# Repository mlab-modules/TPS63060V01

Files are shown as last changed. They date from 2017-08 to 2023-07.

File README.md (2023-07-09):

# MLAB TPS63060V01A Module

The MLAB TPS63060V01A module is based on [TPS63060](https://www.ti.com/lit/ds/symlink/tps63060.pdf?HQS=TI-null-null-digikeymode-df-pf-null-wwe&ts=1614085886440) integrated circuit from Texas Instruments. This circuit is a synchronous step-down (buck-boost) converter, capable of regulating the output voltage whether the input voltage is either higher or lower than the output voltage.

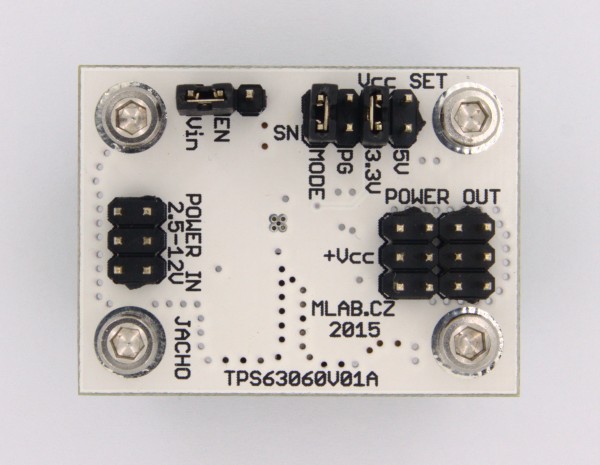
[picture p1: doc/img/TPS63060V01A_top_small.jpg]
TPS63060V01A


### TPS63060
The TPS63060 is a highly efficient, fully integrated, synchronous buck-boost converter designed for a wide range of applications. This circuit has an internal switching transistor, which allows it to achieve high efficiency at low loads.

The TPS63060 operates in automatic PFM/PWM switching mode, switching between PFM (Pulse Frequency Modulation) mode at low loads for efficiency optimization, and PWM (Pulse Width Modulation) mode at higher loads for better voltage regulation.

### Basic Parameters:
- Input voltage: 2.5 V to 12 V
- Output voltage: 2.5 V to 8 V
- Maximum current for internal transistor: 2 A
- Output voltage selectable at 3.3 V or 5 V (by jumper placement)
- Pin for converter activation: EN
- Pin for power saving mode and synchronization: PS/SYNC

Users can choose between an output voltage of 3.3 V or 5 V using a jumper setting.

A significant feature of the module is the ability to activate and deactivate the converter via the EN (enable input) pin. This is especially useful in applications where power is supplied by batteries, and there is a need to protect them from deep discharge.

A unique feature of the module is also the presence of the PS/SYNC pin, labeled as SN. This allows the power saving mode of the converter to be activated if the current draw is less than 100 mA. This pin can also be used to synchronize the converter with an external clock signal.

## Possible Applications
Due to its range of input and output voltages and the ability to regulate, this module is suitable for various applications. It can be used to power low voltage devices from higher voltage batteries or vice versa. Its versatility makes it suitable for a wide range of devices from mobile devices to IoT applications to industrial systems. The power saving mode and the ability to activate/deactivate the converter also support its use in devices where power consumption efficiency is important.

For more detailed information on the functionality of the TPS63060 circuit, we recommend studying its [technical datasheet](https://www.ti.com/lit/ds/symlink/tps63060.pdf?HQS=TI-null-null-digikeymode-df-pf-null-wwe&ts=1614085886440). If you have any further questions, feel free to contact us via email or [Github discuss page](https://github.com/orgs/MLAB-project/discussions) for more information and resources.

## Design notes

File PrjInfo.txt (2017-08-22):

[InfoShortDescription.en]
BUCK-BOOST CONVERTER

[InfoShortDescription.cs]
Snižující/Zvyšující měnič

[InfoLongDescription.en]
The drive uses the TPS63060 circuit. The input voltage range of 2.5 V - 12V. The output voltage of 3.3 V, 5 V. 

[InfoLongDescription.cs]
Měnič využívá obvodu TPS63060. Vstupní napětí v rozsahu 2,5 V - 12V. Výstupní napětí 3,3 V, 5 V. 

[InfoBuyUST]
http://www.ust.cz/shop/product_info.php?cPath=22_35&products_id=258

[End]

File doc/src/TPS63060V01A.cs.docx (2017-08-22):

Snižující / zvyšující měnič

Jan Chroust

## Měnič využívá obvodu TPS63060. Vstupní napětí v rozsahu 2,5 V - 12V. Výstupní napětí 3,3 V, 5 V.

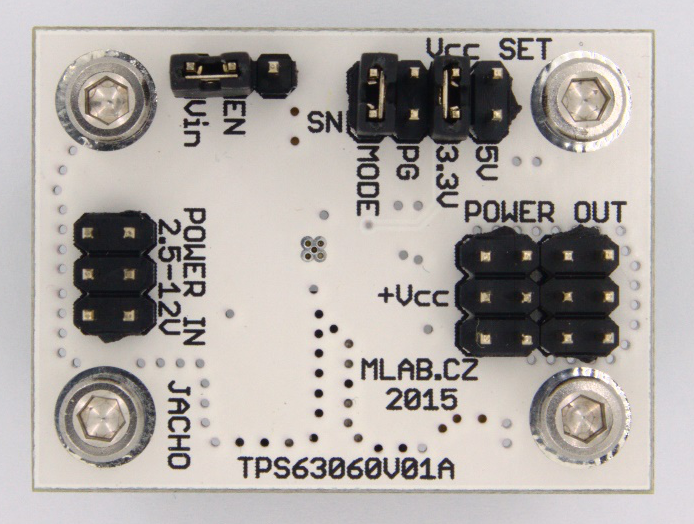
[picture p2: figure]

# 1. Technické parametry

Parametr | Hodnota | Poznámka
Napájení | 2,5 V – 12 V
Výstupní napětí | 3,3V nebo 5 V | Změnou součástek 2,5 V – 8 V
Integrovaný obvod | TPS63060
Imax vnitřním tranzistorem | cca 2,25 A
Rozměry | 29.97 x 40.13 x 16 mm | Výška nad základní deskou

# 2. Popis konstrukce

Základ celého modulu tvoří obvod TPS63060, který umožňuje měnit vstupní stejnosměrné napětí v rozsahu 2,5 V až 12 V na výstupní napětí v rozsahu 2,5 V až 8 V. Maximální proud pro vnitřní tranzistor je cca 2,25A. Modul je standardně osazen rezistory pro fixní nastavení výstupního napětí 3,3 V nebo 5 V, které se volí pomocí jumperu.

Pin EN (enable input) slouží pro aktivaci měniče. Tento vývod je důležitý pro aplikace, které se napájejí z akumulátorů a je potřeba zajistit, aby se měnič včas vypnul a nedošlo k pod vybití akumulátorů. Pro hlídání meze vypnutí měniče je využit obvod APX809 s mezní hodnotou 2,6V. Toto napětí je vhodné pro napájení z jednoho Li-on článku.

Modul má vyvedený pin PS/SYNC na hřebínek označení SN. V případě, kdy je na pozici MODE vložen jumper, tak je modul v úsporném režimu. Tento režim se začne projevovat při odběru proudu pod 100 mA, kdy se měnič může vypínat, pokud výstupní kondenzátory udrží nastavené výstupní napětí. Úsporný režim je deaktivován nastavením log. 1 na pin SN. Tento pin je možné využít i pro synchronizaci měniče vnějším hodinovým signálem.

Podrobný popis funkcí a módů obvodu TPS63060 je možné podrobně nastudovat v technickém listu obvodu.

## 2.1. Mechanická konstrukce

Modul obsahuje úchytné šroubky ve všech rozích v rozteči MLAB (10.16mm).

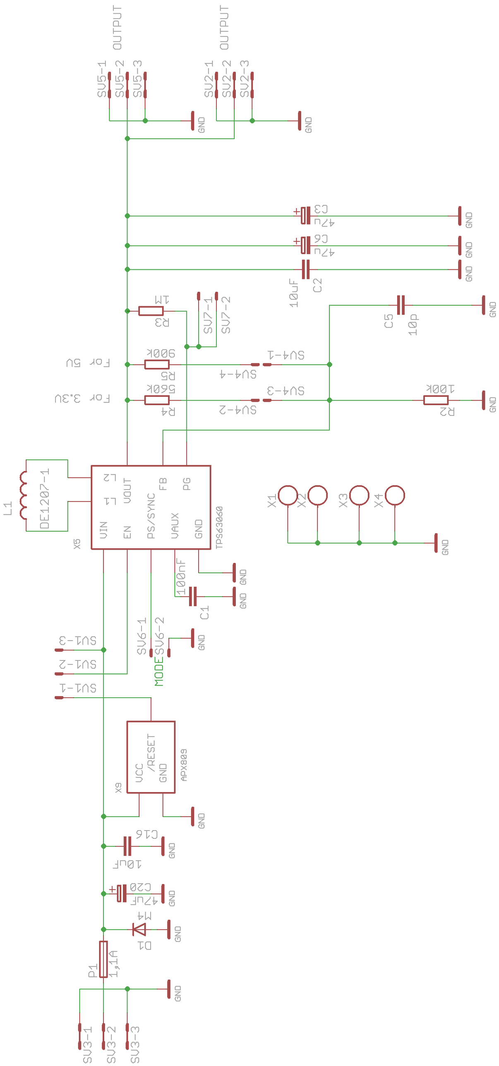
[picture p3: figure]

## 2.2. Osazení a oživení

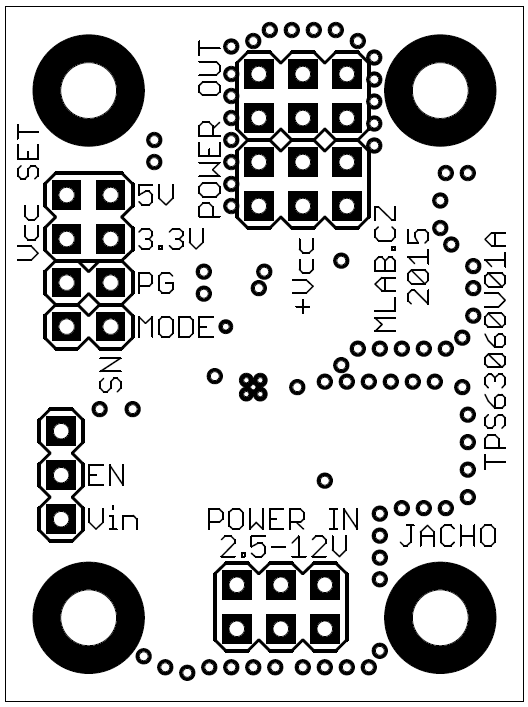
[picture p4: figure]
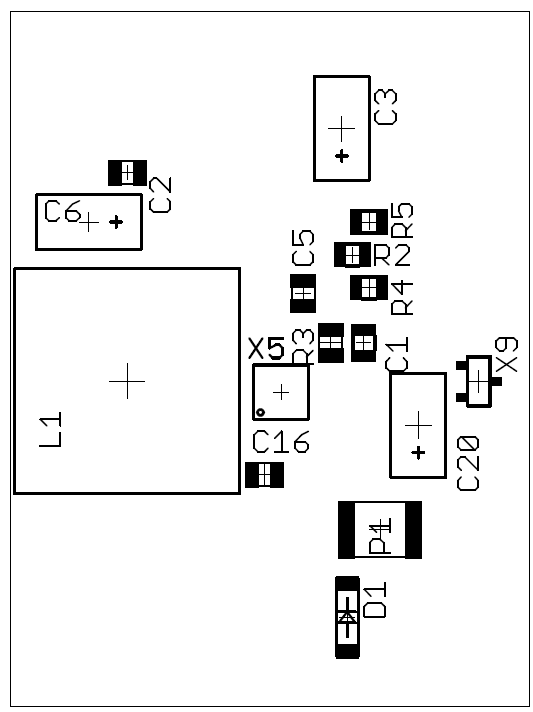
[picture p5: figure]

## 2.3. Osazení

Označení | Typ | Pouzdro | Počet
C1 | 100nF | C0805 | 1
C2, C16 | 10uF | C0805 | 2
C3, C6, C20 | 47u | C | 3
C5 | 10p | C0805 | 1
D1 | M4 | SMA | 1
L1 | DE1207-1 | DE1205-10 | 1
P1 | 1,1A | 1812 | 1
R2 | 100k | 805 | 1
R3 | 1M | 805 | 1
R4 | 560k | 805 | 1
R5 | 909k | 805 | 1
SV1 | JUMP1X3 | MA03-1 | 1
SV2, SV3, SV5 | JUMP2X3 | MA03-2 | 3
SV4 | JUMP2X2 | MA02-2 | 1
SV6, SV7 | JUMP2X1 | MA02-1 | 2
X1 - X4 | SROUB3M | SROUB3M | 4
X5 | TPS63060 | SON10 | 1
X9 | APX809 | SOT23 | 1

Jumper na pozici: MODE, 3,3 V a EN-Vin

Při osazování: zvýšená pozornost na zaletování X5, modul je možné mýt

TPS63060V01A / 2015-11-05 / jacho/ http://www.mlab.cz 4 / 4

TPS63060V01A MLAB

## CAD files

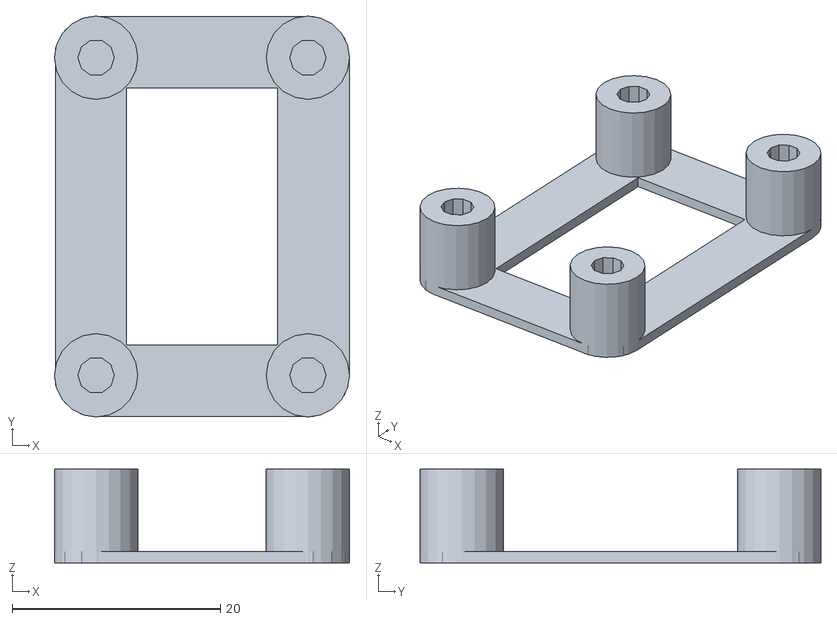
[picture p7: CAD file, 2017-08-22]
cad/3x4MLAB_frame.stl
28.3 x 38.5 x 9.00

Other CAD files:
cad/src/3x4MLAB_frame.scad

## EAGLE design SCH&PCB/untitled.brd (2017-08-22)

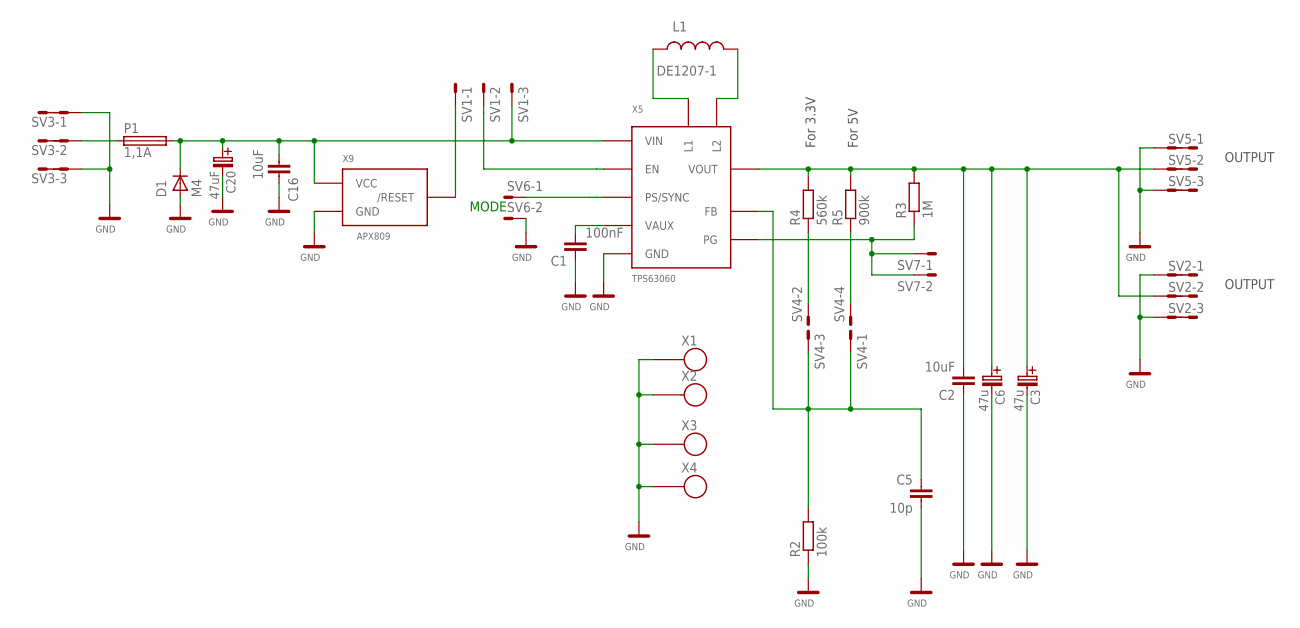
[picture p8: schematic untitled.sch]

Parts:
C1: 100nF; C0805
C2, C16: 10uF; C0805
C3, C6: 47u; C
C5: 10p; C0805
C20: 47uF; C
D1: M4; SMA
L1: DE1207-1; DE1205-10
P1: 1,1A; 1812
R2: 100k; 0805
R3: 1M; 0805
R4: 560k; 0805
R5: 900k; 0805
SV1: MA03-1
SV2, SV3, SV5: MA03-2
SV4: MA02-3; MA02-2
SV6, SV7: MA02-1
X1, X2, X3, X4: SROUB3M
X5: TPS63060; SON10
X9: APX809; SOT23

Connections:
+BAT2: C16.2, C20.+ (C_EL+), D1.K (C), P1.2, SV1.3, X5.2 (VIN), X9.3 (VCC)
GND: C1.1, C2.1, C3.- (C_EL-), C5.2, C6.- (C_EL-), C16.1, C20.- (C_EL-), D1.A, R2.1, SV2.1, SV2.2, SV2.5, SV2.6, SV3.1, SV3.2, SV3.5, SV3.6, SV5.1, SV5.2, SV5.5, SV5.6, SV6.2, X1.P$1, X2.P$1, X3.P$1, X4.P$1, X5.7 (GND), X5.11 (GND), X5.12 (GND), X5.13 (GND), X5.14 (GND), X5.15 (GND), X5.16 (GND), X5.17 (GND), X5.18 (GND), X5.19 (GND), X5.21 (GND), X5.P$1 (GND), X5.P$2 (GND), X5.P$3 (GND), X5.P$4 (GND), X5.P$5 (GND), X9.1 (GND)
unnamed: SV1.1, X9.2 (/RESET)
unnamed: SV1.2, X5.3 (EN)
unnamed: P1.1, SV3.3, SV3.4
unnamed: C5.1, R2.2, SV4.1, SV4.3, X5.8 (FB)
unnamed: R3.1, SV7.1, SV7.2, X5.5 (PG)
unnamed: R4.1, SV4.2
unnamed: C2.2, C3.+ (C_EL+), C6.+ (C_EL+), R3.2, R4.2, R5.2, SV2.3, SV2.4, SV5.3, SV5.4, X5.9 (VOUT)
unnamed: R5.1, SV4.4
unnamed: SV6.1, X5.4 (PS/SYNC)
unnamed: C1.2, X5.6 (VAUX)
unnamed: L1.P$1 (1), X5.1 (L1)
unnamed: L1.P$2 (2), X5.10 (L2)

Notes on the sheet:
OUTPUT
MODE
For 5V
For 3.3V

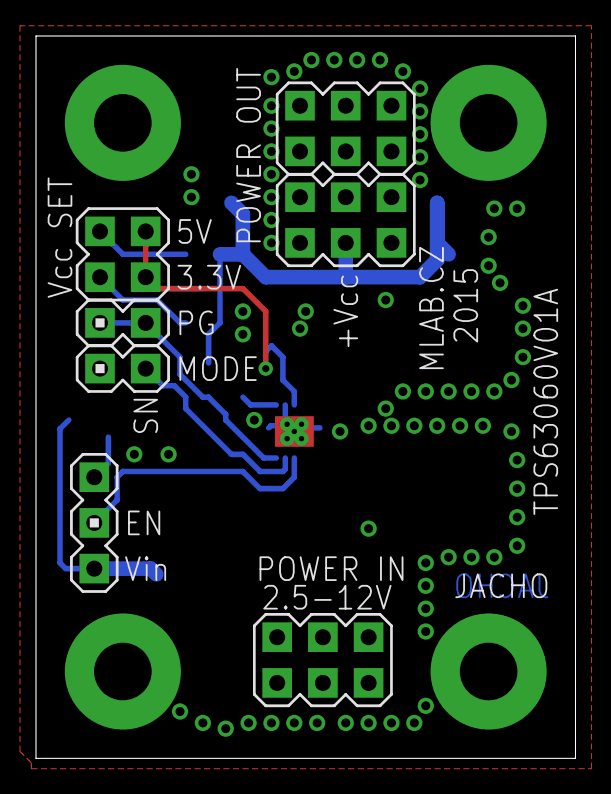
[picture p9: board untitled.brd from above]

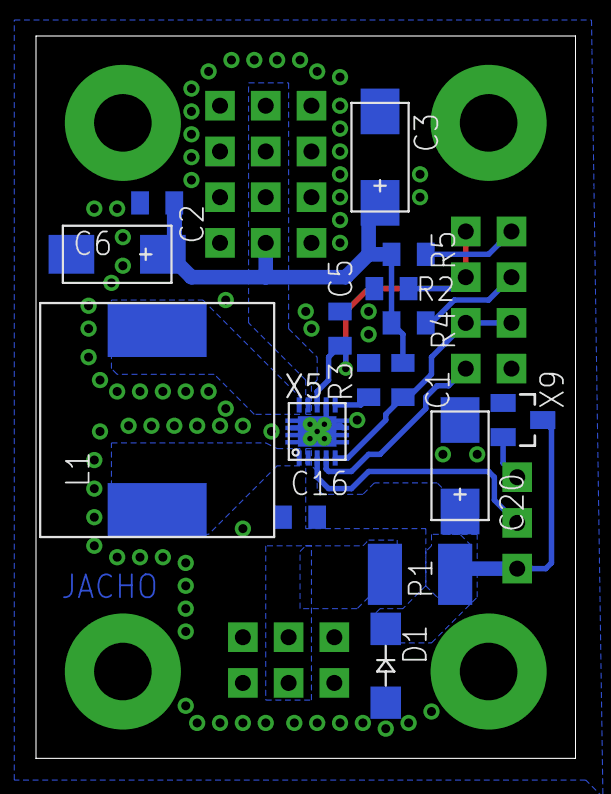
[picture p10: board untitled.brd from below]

Board: 2 copper layers, 30.0 x 40.1 mm, 27 parts (16 on the bottom side), 14 nets.

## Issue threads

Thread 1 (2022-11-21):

Inaccurate voltage output

kaklik, 2022-11-21:
Výstupní napětí z modulu má poměrně výrazný rozptyl hodnot, který komplikuje konstrukci některých zařízení. Pozorovaný rozptyl hodnot byl od 3.2V do cca 3.5V.

Je možné že za problémem stojí nepřesnost hodnot rezistorů použitých v děliči. Druhou možností je nepřesnost zpětné vazby použitých kusů IO. Případně to může být kobinace obou těchto možností.  Důsledkem je že např. v konstrukci https://github.com/ODZ-UJF-AV-CR/Li-ion-Charger jsou překročeny maximální provozní napětí displeje.

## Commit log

2017-08-22 rename category folders
    [3x4MLAB_frame.scad, 3x4MLAB_frame.stl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]
2017-08-22 rename files and module folders
    [3x4MLAB_frame.scad, 3x4MLAB_frame.stl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]
2017-08-22 create hw folder
    [TPS63060V01A-B_Cu.gbr, TPS63060V01A-B_Mask.gbr, TPS63060V01A-Edge_Cuts.gbr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]
2022-04-06 Update actions products
    [TPS63060V01A-B_Cu.gbr, TPS63060V01A-B_Mask.gbr, TPS63060V01A-Edge_Cuts.gbr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]
